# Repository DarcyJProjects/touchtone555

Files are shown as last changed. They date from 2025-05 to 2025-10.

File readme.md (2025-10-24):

# TouchTone555 – NE555 Analogue Stylus Synth

The **TouchTone555** is a fully analogue, NE555-based synthesizer designed for learning about analogue electronics, and a bit of fun too. It was built from scratch as a personal deep-dive into oscillators, signal integrity, analogue filtering, and amplification.

Read the full project write up at: [www.darcyjprojects.xyz](https://www.darcyjprojects.xyz/index.php/2025/04/07/analogue-synth-project-touchtone555/)

[🔗 Share this project on LinkedIn](https://www.linkedin.com/shareArticle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!)



<p>
  This project is open source hardware under the <strong>CERN Open Hardware Licence Version 2 - Strongly Reciprocal (CERN-OHL-S v2)</strong>.
</p>
Open Source Hardware Logo

⚖️**Disclaimer:** This synthesizer was developed as a purely educational project to explore analogue electronics and sound synthesis. It is an independent work inspired by the vintage Stylophone, with no affiliation to Dubreq Ltd. or the original Stylophone product. All trademarks remain the property of their respective owners, and no copyright or trademark infringement is intended.

---

## 📑 Table of Contents

* 🎛 [Features](#-features)

* 📷 [Demo](#-demo)

* 📜 [Licence](#-licence)

* ⚡[How It Works](#how-it-works)

* 🛠️ [Build Instructions](#%EF%B8%8F-build-instructions)
  
  * 🧾 [What You’ll Need](#-what-youll-need)
  
  * 🪛 [Assembly](#-assembly)

* 📂 [Repo Structure](#-repo-structure)

* 💬 [Feedback & Contributions](#-feedback--contributions)

* 🔗 [Acknowledgements](#-acknowledgements)

* 🧠 [Why I Built This](#-why-i-built-this)

---

## 🎛 Features

- Based on the NE555 in astable multivibrator configuration as the main audio oscillator
- Individually tuneable keys with trim potentiometers
- Touch interface for the keys with a stylus
- Octave switching via capacitor bank selection
- Vibrato modulation using an RC oscillator on the 555's CV pin
- Push-pull amplifier output with an LM386 buffer stage
- Onboard speaker with volume control, as well as a headphone output
- Custom designed PCB, with a descriptive silkscreen



---

## 📷 Demo

Check out the demo video here:<br>
👉 [Watch the video](https://www.youtube.com/watch?v=lvPiY5EYj-0)<br>
[](https://www.youtube.com/watch?v=lvPiY5EYj-0)<br>
🎵 Features a cover of Littleroot Town from Pokémon.

---

## 📜 Licence

This project is licenced under the **CERN-OHL-S v2 Strongly Reciprocal**.  

You are free to:

- **Study** and **modify** the design.

- **Make** and **sell** your own copies.

- **Distribute** modified versions — **as long as you:**
  
  - **Use the same CERN-OHL-S v2 licence** (strong reciprocity), and
  
  - **Provide attribution to the original author**, and
  
  - **Include the original source files and any modifications**.

For full details, see the [LICENCE.txt](https://github.com/DarcyJProjects/touchtone555/blob/main/LICENCE.txt) file.



---

## ⚡How It Works

The TouchTone555 generates sound using an NE555 timer IC which is configured as an astable multivibrator. 

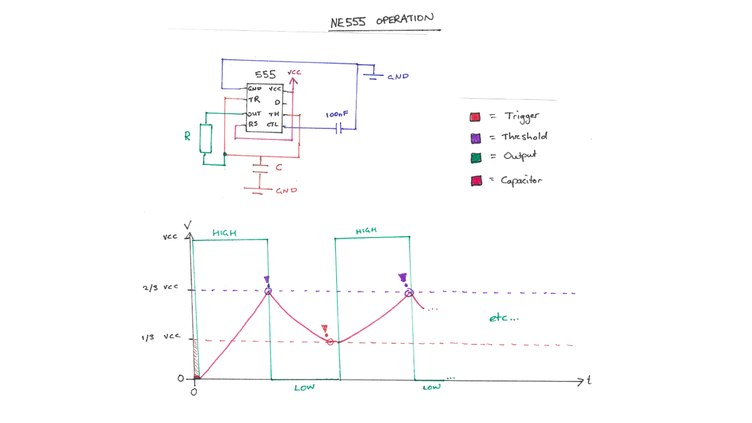
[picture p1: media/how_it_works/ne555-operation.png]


Each key forms part of a series resistor network, which controls the oscillator’s frequency when the circuit is completed by touching a key with the stylus. The pitch is determined by which key is touched, and the selected octave capacitor.

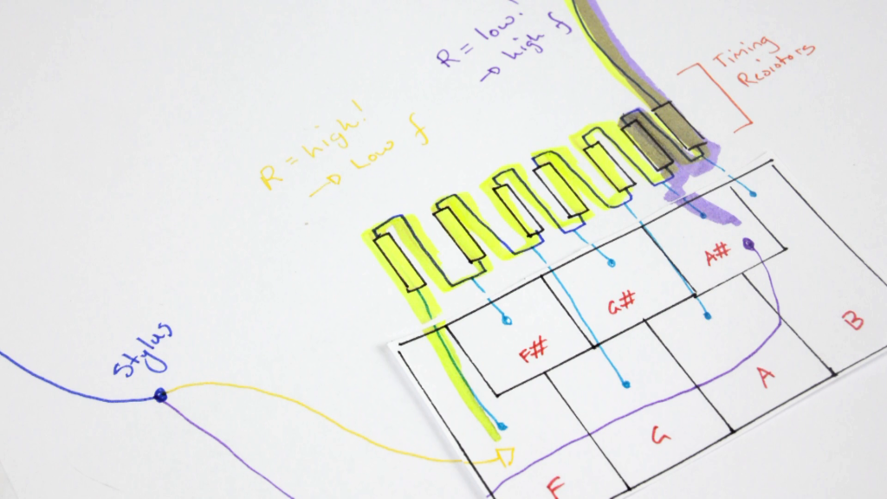
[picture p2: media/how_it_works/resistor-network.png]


Octave switching is achieved by toggling between banks of capacitors connected to the NE555. The more capacitance connected (capacitors in parallel), the lower the resulting octave.

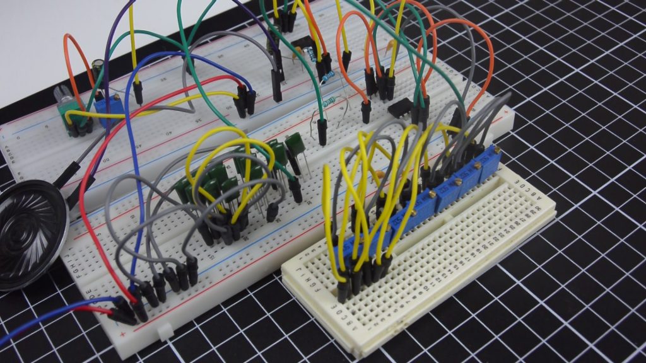
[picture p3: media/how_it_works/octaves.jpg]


Vibrato is achieved by modulating the NE555's control voltage pin using a separate RC oscillator, which uses RC (resistor-capacitor) pairs, capacitors, and a transistor to generate the low-frequency signal. The vibrato depth (or "mix") can be adjusted with the on-board trim potentiometer.



The output signal is then passed through an LM386 and then through a simple push-pull amplifier to drive the onboard speaker and/or headphones. The LM386 acts as a buffer to ensure any loading from the amplifier doesn't affect the NE555 through its output pin. The supply voltage to the NE555 is also filtered with a resistor and capacitor to reduce any periodic voltage drop introduced by the amplifier.

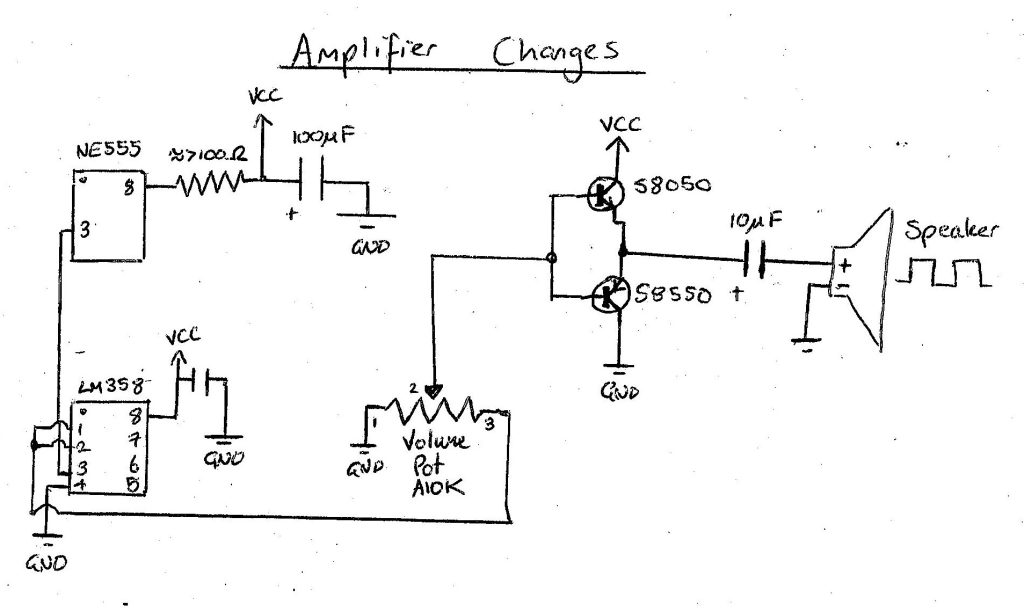
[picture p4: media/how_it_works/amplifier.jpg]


The power supply circuitry is simple: it supports a 9V DC input via either a JST connector, or a DC barrel jack. Two diodes prevent reverse polarity and ensure that the inputs cannot backfeed each other. 

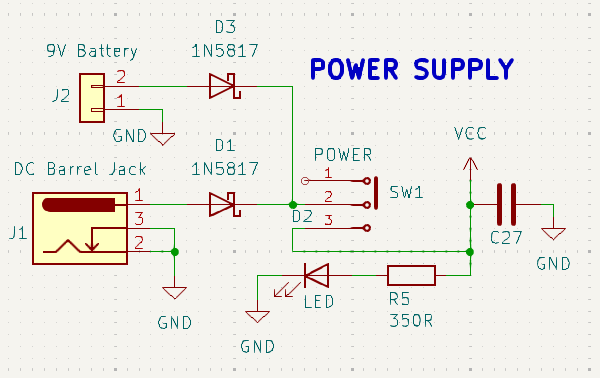
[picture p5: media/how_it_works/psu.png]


This project demonstrates the core concepts of oscillation, modulation, and amplification - no microcontroller required!

👉 For a full breakdown and more detail explanations, you can read the write-up here: [www.darcyjprojects.xyz](https://www.darcyjprojects.xyz/index.php/2025/04/07/analogue-synth-project-touchtone555/)

---

## 🛠️ Build Instructions



### 🧾 What You’ll Need

- All components as outlined in the [BOM (Bill-of-Materials)](https://github.com/DarcyJProjects/touchtone555/blob/main/hardware/bom.md)
- To find the correct switches, speaker, audio jack, etc, see [Miscellaneous Parts](https://github.com/DarcyJProjects/touchtone555/blob/main/hardware/misc_parts.md)
- PCB (See [KiCad Project](https://github.com/DarcyJProjects/touchtone555/tree/main/hardware))
- Soldering iron and solder
- 9V Battery and connector or DC jack with 9V supply

⚠️ **Note:** I recommend selecting a **lead-free surface finish** (e.g., LeadFree HASL) when ordering the PCB as the stylus will put microscopic scratches in the exposed key pads during use. This could potentially produce harmful lead dust over time. Therefore, I highly recommend choosing lead-free!

### 🪛 Assembly

- Read each step fully before completing it to make sure you've read any handy tips :)
1. **Order the PCB**<br>
   The KiCad project files (and pre-exported gerber files) are located in [/hardware](https://github.com/DarcyJProjects/touchtone555/tree/main/hardware).

2. **Solder components in order**<br>
   Start with the smallest passive components (resistors, monolithic capacitors, diodes), then IC sockets, transistors, connectors/jacks/switches, ceramic and polyester capacitors, and finally the DC jack, trim potentiometers and the volume potentiometer.
   
   Soldering them systematically from smallest height to largest makes it a lot easier! Follow the component designators on the board, and in the BOM to make sure you are matching the correct values and components.
   
   Try your best not to get any solder on the exposed key pads, if you're nervous, you  can tape over them with some electrical or painters tape until you're finished soldering.
   
   For the polyester octave capacitors, try to get the values matched to each other as closely as possible as a small variance of 0.5 nF can throw off the pitch. This is less important for the lower octaves, but the highest octave with the single capacitor matters the most.
   
   For the vibrato monolithic capacitors, you can start with soldering the top three in, and adding the lower two if you want increase the vibrato frequency.

3. **Attach speaker & power**<br>
   The synth is designed to run on 9VDC, so I recommend using a 9V battery with a 9V battery to JST connector.

4. **Stylus**<br>
   
   In [/hardware](https://github.com/DarcyJProjects/touchtone555/tree/main/hardware), there is a 3D model of a stylus if you'd like to 3D print one, otherwise, a crocodile lead works really well too - just be careful not to push down too aggressively as to not damage the key pads.
   
   If you take the 3D model route, you can feed a thin gauge wire through the hole in the centre of the stylus, and solder a small piece of metal to the wire at the tip of the stylus. I used a mini spade connector which I soldered and then bent around the tip. I smoothed out the contact surface by creating a sphere of solder. You'll need to tape the tip to the stylus to ensure it doesn't come off. This stylus isn't perfect, but it works :)

5. **Tune keys**<br>
   Use a tuner app (with a chromatic mode) or oscilloscope to set the individual key pitches via the blue trim potentiometers.
   
   Set the octave to the lowest octave (lowest position on the octave switch) and then start tuning with the highest note on the keyboard, which corresponds to the right-most trim pot. Turning it clockwise will increase the pitch, and anticlockwise will decrease the pitch. You are aiming for the highest note (in the lowest octave) to be E6.
   
   Then work your way leftwards, one potentiometer at a time, reducing the pitch by one semitone each time.
   
   Remember, as this is a series resistor network, adjusting the pitch of one potentiometer will adjust the pitch of all the other keys to the left of that key. This is why you should work right to left.

6. **Vibrato depth**<br>
   By turning the vibrato depth trim pot, you can slightly adjust how strong the vibrato effect is. The change with each turn is minimal, so you'll need to turn it a lot to get any real difference. 

7. **Have fun!**

---

## 📂 Repo Structure

TouchTone555/<br>├── hardware/ # KiCad project + Gerbers + Stylus 3D model<br>├── media/ # Photos, demo videos, renders, etc<br>├── LICENCE # CERN-OHL-S v2<br>└── README.md # this file!<br>

---

### 💬 Feedback & Contributions

Feel free to fork, share, and build your own!<br>
If you build one, I’d love to see it - tag me on [LinkedIn](https://www.linkedin.com/in/darcywdjohnson/).

---

### 🔗 Acknowledgements

- This is an independent work inspired by the classic Stylophone with no affiliation to Dubreq Ltd. or the original Stylophone product. All trademarks remain the property of their respective owners, and no copyright or trademark infringement is intended.
- "Littleroot Town", composed by Gō Ichinose, Junichi Masuda, & Morikazu Aoki, from *Pokémon Ruby, Sapphire, & Emerald* (© Nintendo / Game Freak), is used under fair use as part of an educational demonstration.

---

## 🧠 Why I Built This

This was a personal challenge to push my understanding of analogue electronics beyond textbooks — especially in:

- Oscillator design
- Filtering
- Operational amplifiers
- Audio amplifiers
- Impedance buffering
- PCB design with custom exposed planes (the key pads)
- PCB footprint design


---

🛠️ Built for learning.<br>
❤️ Shared with the community.<br>
🔧 Darcy — [www.darcyjprojects.xyz](https://www.darcyjprojects.xyz)

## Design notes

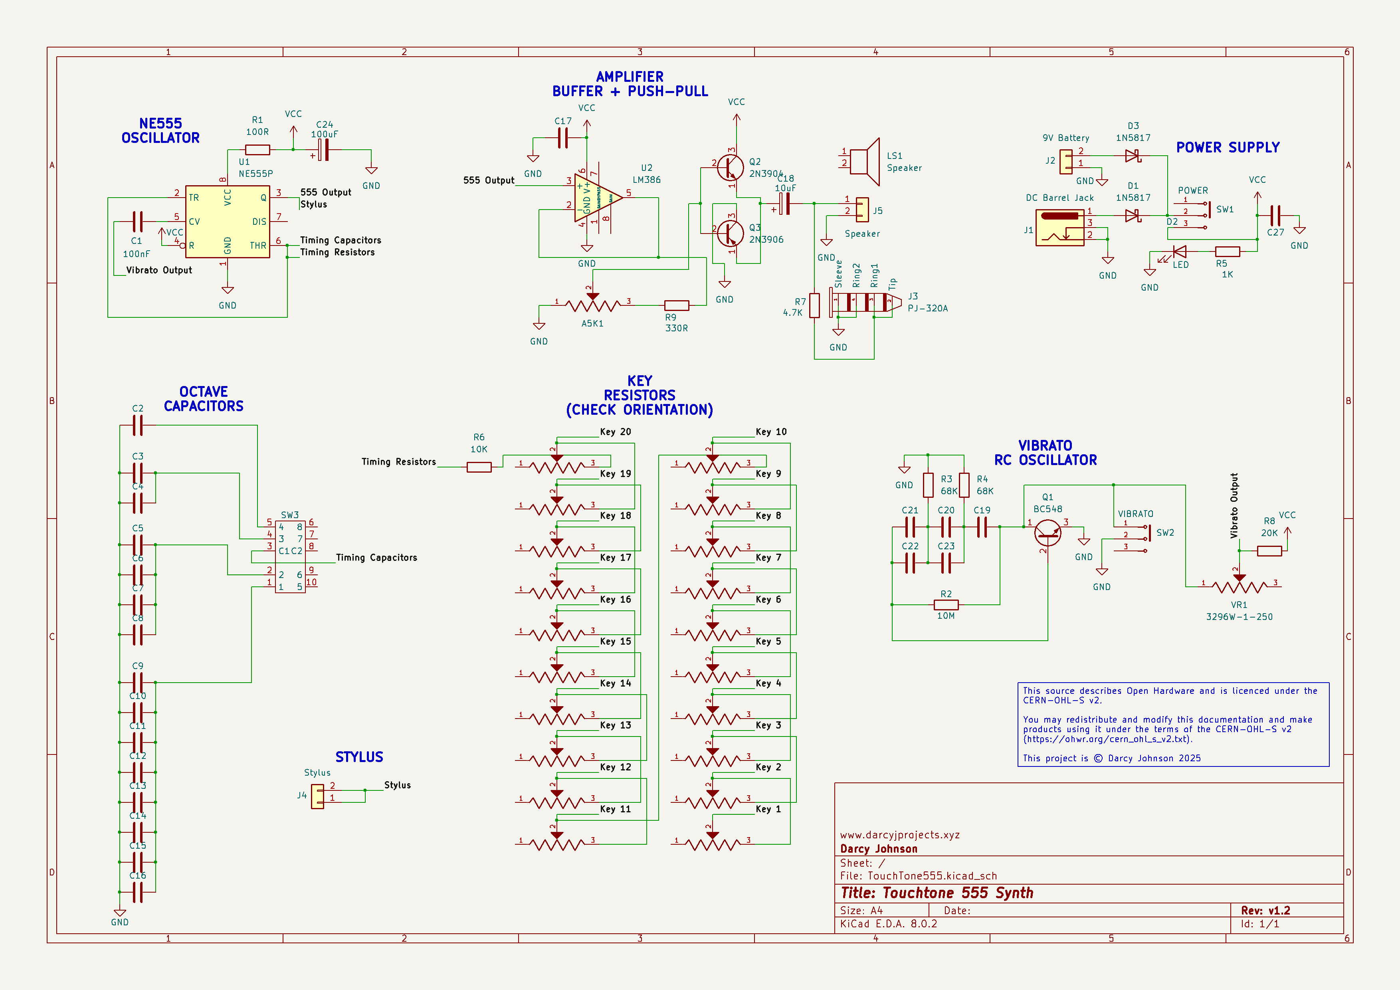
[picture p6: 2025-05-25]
media/schematic.png

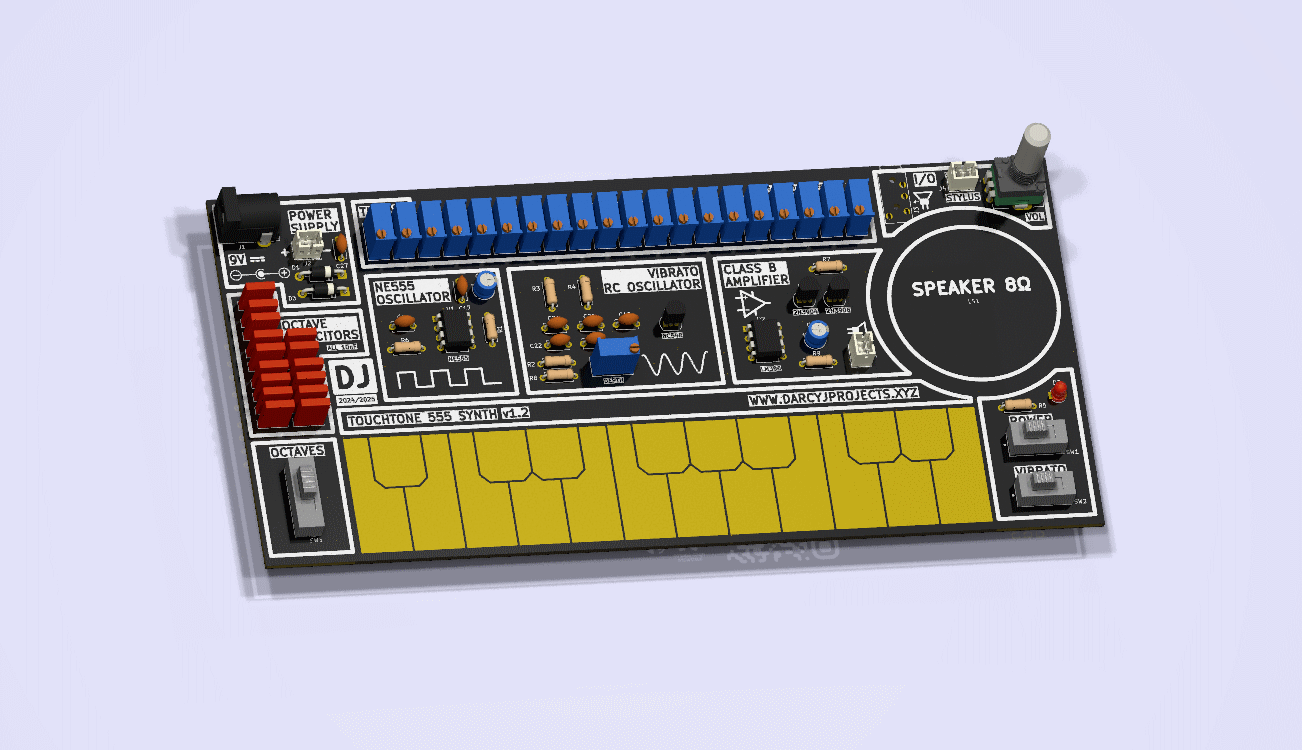
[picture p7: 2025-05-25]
media/board render.png

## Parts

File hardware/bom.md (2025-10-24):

# BOM– TouchTone555

This file lists the Bill of Materials (BOM) - the components required to complete this project.
The regular csv BOM can be viewed here: [Bill of Materials.csv](https://github.com/DarcyJProjects/touchtone555/blob/main/hardware/Bill%20of%20Materials.csv)

---

## Semiconductors

| Qty | Part | Notes |
| --- | --- | --- |
| 2 | 1N5817 | Schottky diode, DO-41 |
| 1 | 2N3906 | PNP, TO-92 |
| 1 | 2N3904 | NPN, TO-92 |
| 1 | BC548 | NPN, TO-92 |
| 1 | LM386 | DIP-8 |
| 1 | NE555P | DIP-8 |
| 1 | LED (any colour) | 3 mm |

### Resistors

| Qty | Value  |
| --- | --- |
| 1 | 100 Ω  |
| 1 | 330 Ω  |
| 1 | 1 kΩ |
| 2 | 10 kΩ  |
| 2 | 68 kΩ  |
| 1 | 4.7 kΩ |
| 1 | 10 MΩ  |

### Potentiometers / Trimmers

| Qty | Type | Value / Model | Notes |
| --- | --- | --- | --- |
| 20  | Trimmer (3296W) | 5 kΩ | |
| 1 | Trimmer (3296W) | 10 kΩ | |
| 1 | Rotary Potentiometer (A5K RK097) | 5 kΩ | [**See Misc Parts**](https://github.com/DarcyJProjects/touchtone555/blob/main/hardware/misc_parts.md) |

### Capacitors

| Qty | Value  | Type / Notes |
| --- | --- | --- |
| 15  | 10 nF  | Green polyester capacitors (rectangular) - do not use ceramic (poor stability). |
| 8 | 100 nF | Ceramic disc |
| 1 | 10 µF  | Electrolytic, radial |
| 1 | 100 µF | Electrolytic, radial |

### Connectors and Jacks

| Qty | Part | Description |
| --- | --- | --- |
| 1 | DC Barrel Jack | [**See Misc Parts**](https://github.com/DarcyJProjects/touchtone555/blob/main/hardware/misc_parts.md) |
| 3 | JST-PH 2-pin | Stylus, speaker, and 9 V battery connector |
| 1 | PJ-320A | 3.5 mm audio jack [**See Misc Parts**](https://github.com/DarcyJProjects/touchtone555/blob/main/hardware/misc_parts.md) |

### Switches

| Qty | Part | Description |
| --- | --- | --- |
| 2 | 2 Position Slide Switch (SPDT) | Power and vibrato switch [**See Misc Parts**](https://github.com/DarcyJProjects/touchtone555/blob/main/hardware/misc_parts.md) |
| 1 | 4 Position Slide Switch (2P4T) | Octave switch [**See Misc Parts**](https://github.com/DarcyJProjects/touchtone555/blob/main/hardware/misc_parts.md) |

### Speaker

| Qty | Part | Description |
| --- | --- | --- |
| 1 | Speaker | 8 Ω, 2W 40 mm [**See Misc Parts**](https://github.com/DarcyJProjects/touchtone555/blob/main/hardware/misc_parts.md) |

---

> 💡 *Note:* Compare parts with the build photos, schematic, and PCB layout to check for correct footprints and sizes. The components listed here are only suggestions and are not guaranteed. Check misc parts file for a detailed look at the less standard components.

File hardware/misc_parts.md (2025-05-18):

# Miscellaneous Components – TouchTone555

This file lists the less standard components that may have slight variations from different sellers, so this information is to help you find the correct parts. The information and photos was taken from the listings I bought the items from (no copyright infringement intended).

---

## Switches

### 🔘 2-Position Slide Switches

- **Name:** Generic mini slide switch
- **Type:** SPDT toggle
- **Voltage:** 5V
- **Current:** 0.3A
- **Used for:** Power switch, Vibrato switch
- **Dimensions (LxWxH):** Approx. 19 x 6 x 13 mm
- **AliExpress:** [https://www.aliexpress.com/item/32812689209.html](https://www.aliexpress.com/item/32812689209.html)

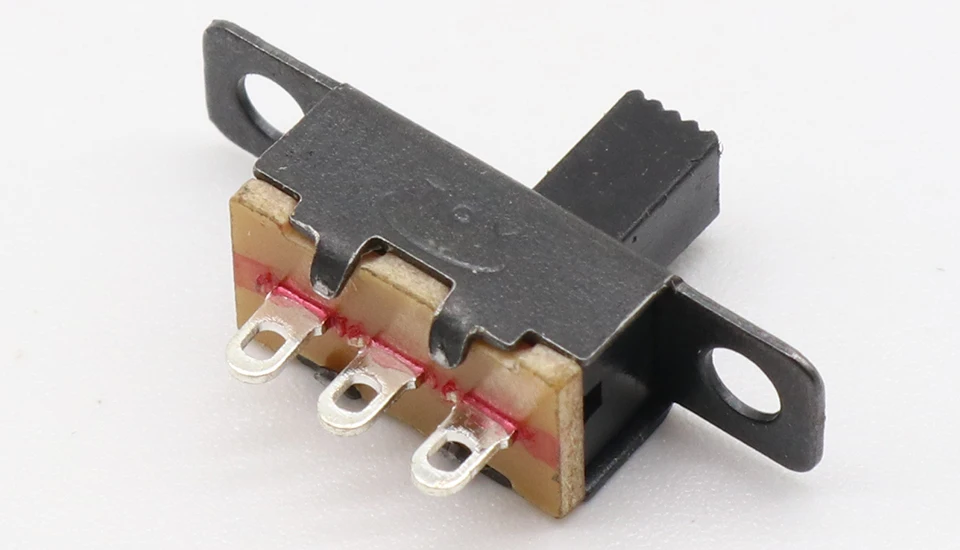
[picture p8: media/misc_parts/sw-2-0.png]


### 🔘 4-Position Slide Switches

- **Name:** SS-24E04 2P4T DIP Type Slide Switch 10 pin
- **Type:** 2P4T
- **Used for:** Octave switch
- **AliExpress:** [https://www.aliexpress.com/item/1005004678559173.html](https://www.aliexpress.com/item/1005004678559173.html)

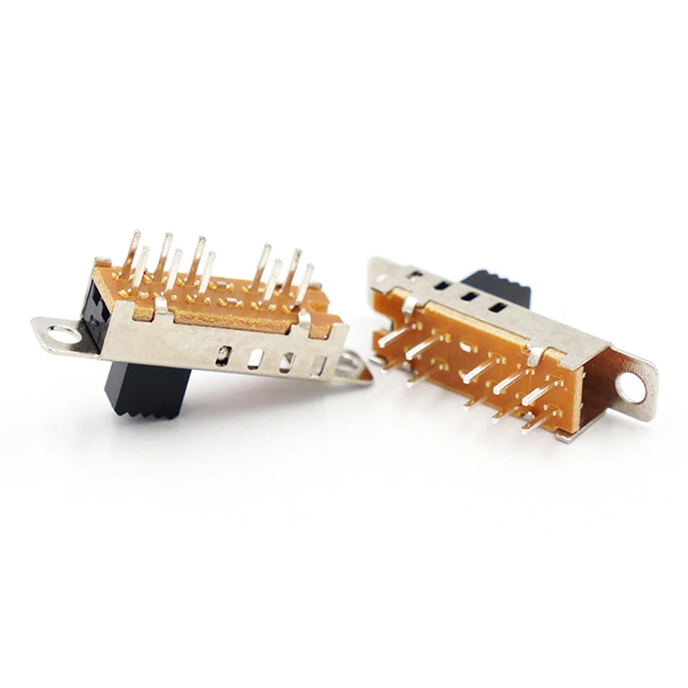
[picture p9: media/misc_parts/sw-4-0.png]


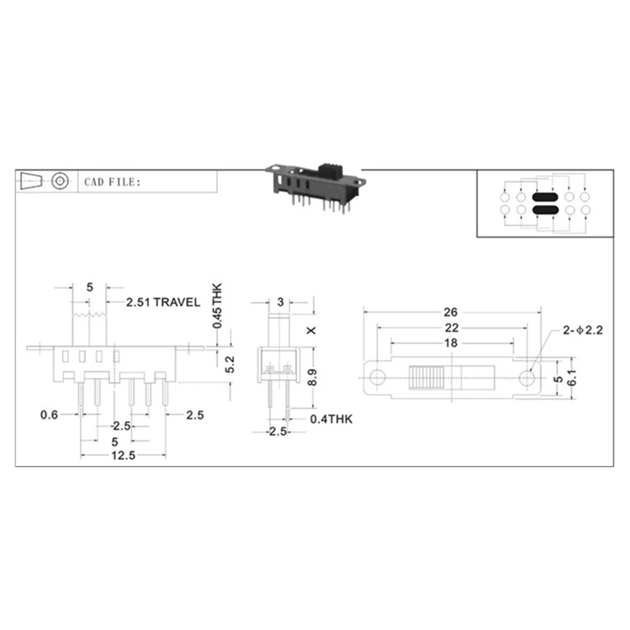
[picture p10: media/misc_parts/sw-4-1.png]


---

## 🔊 Speaker

- **Type:** 8Ω 2W
- **Diameter:** 40 mm
- **AliExpress:** [https://www.aliexpress.com/item/1005006730077789.html](https://www.aliexpress.com/item/1005006730077789.html)

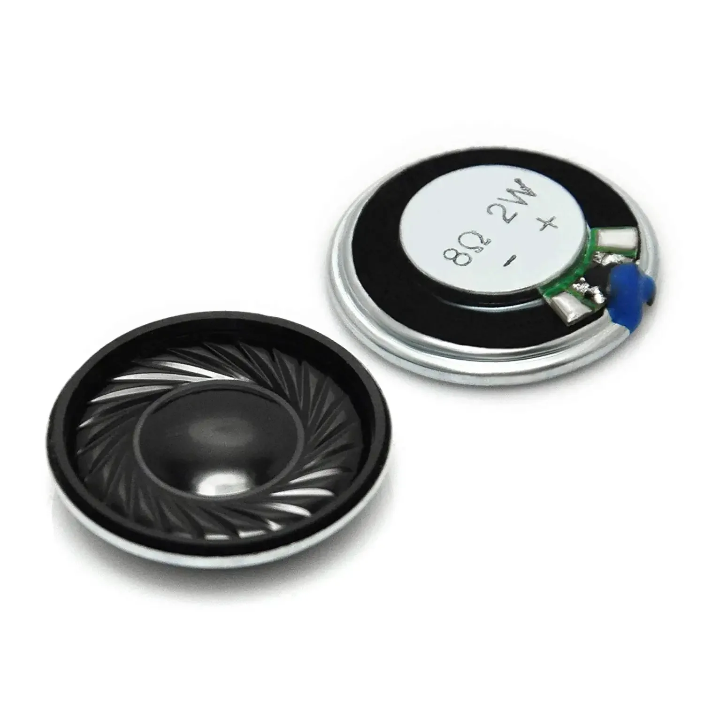
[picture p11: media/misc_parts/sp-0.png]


---

## 🎚️ Volume Potentiometer

- **Type:** B10K (Linear Rotary Potentiometer)
- **Model:** RV09
- **Shaft:** 12.5 mm
- **AliExpress:** [https://www.aliexpress.com/item/1005006089154415.html](https://www.aliexpress.com/item/1005006089154415.html)

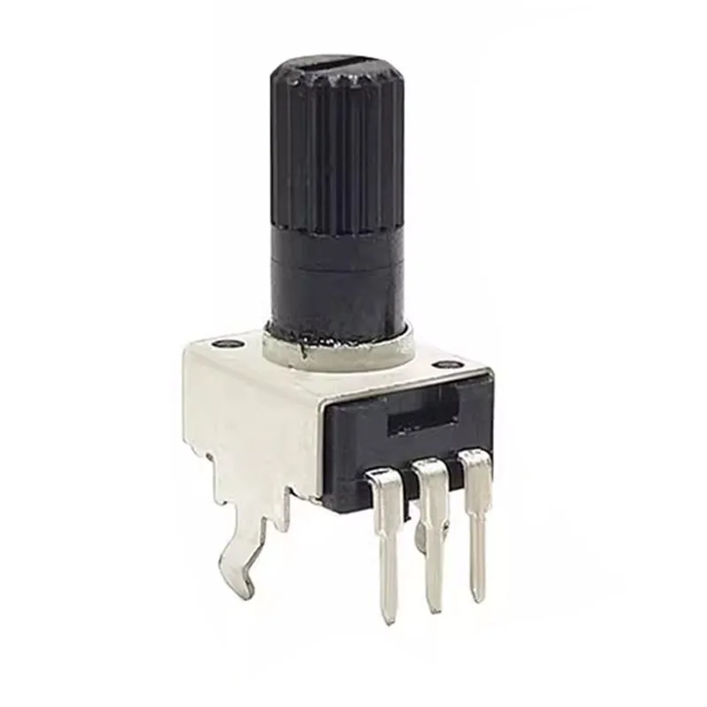
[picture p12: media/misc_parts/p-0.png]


---

## 🎧 Headphone Jack

- **Type:** 3.5 mm stereo audio jack
- **Model:** PJ320A
- **AliExpress:** [https://www.aliexpress.com/item/1005003111662179.html](https://www.aliexpress.com/item/1005003111662179.html)

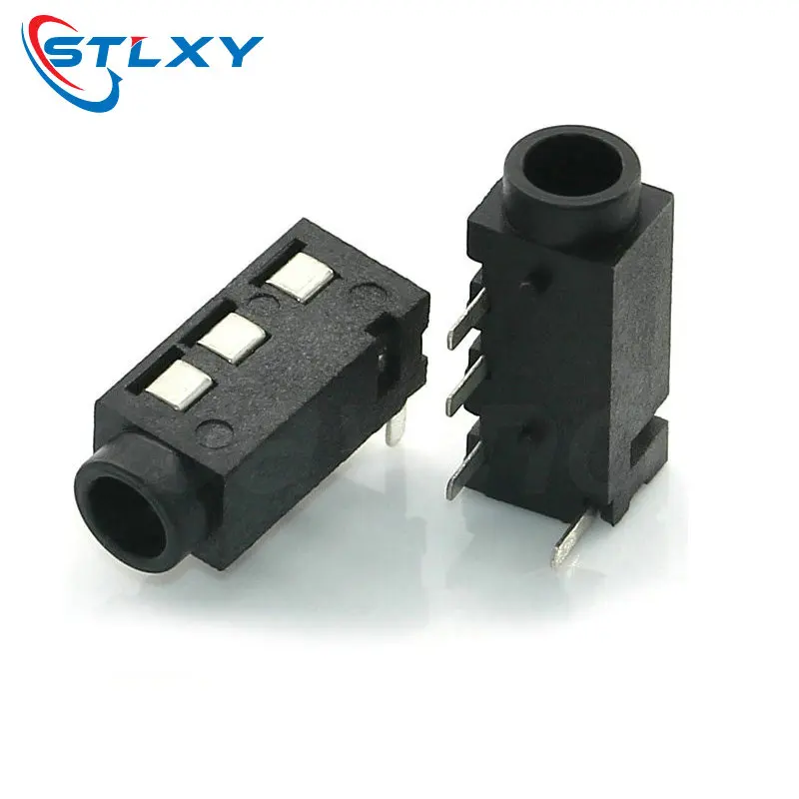
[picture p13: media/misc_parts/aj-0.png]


---

## 🔌 DC Power Jack

- **Name:** DC Power Jack Socket Barrel Right Angle
- **AliExpress:** [https://www.aliexpress.com/item/4001206395694.html](https://www.aliexpress.com/item/4001206395694.html?)

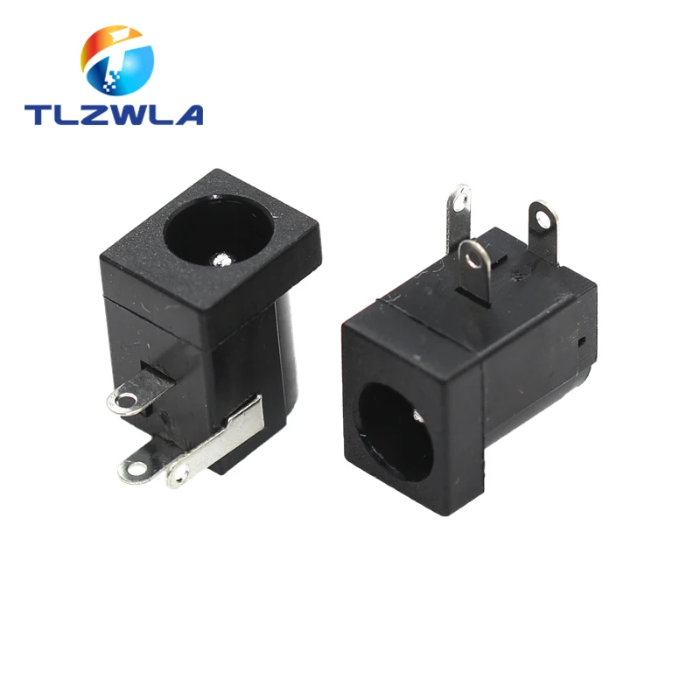
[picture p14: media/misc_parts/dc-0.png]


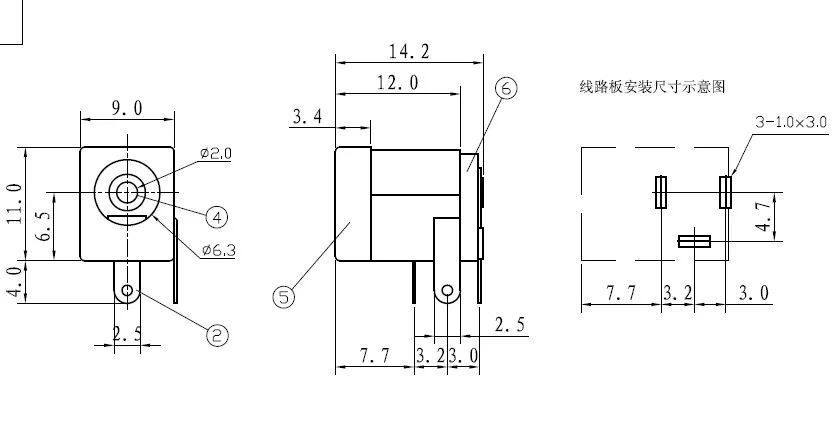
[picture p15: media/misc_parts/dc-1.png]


---

> 💡 *Note:* Exact part numbers and models may vary by region or vendor. These suggestions are the listings I bought my parts from, however, the stock may have changed since my purchase, so carefully reference the PCB footprints and schematic values before purchasing. The components listed here are only suggestions and are not guaranteed.

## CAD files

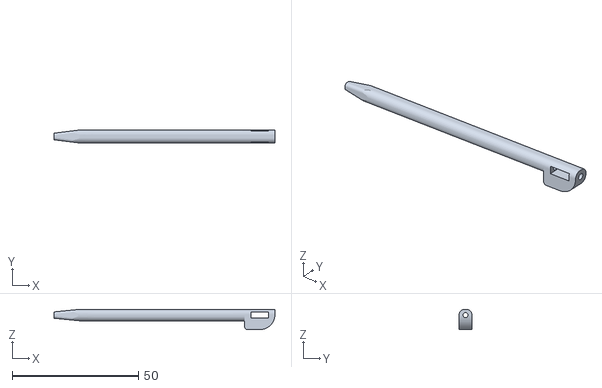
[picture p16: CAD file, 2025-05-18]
hardware/stylus.stl
87.5 x 5.00 x 8.00

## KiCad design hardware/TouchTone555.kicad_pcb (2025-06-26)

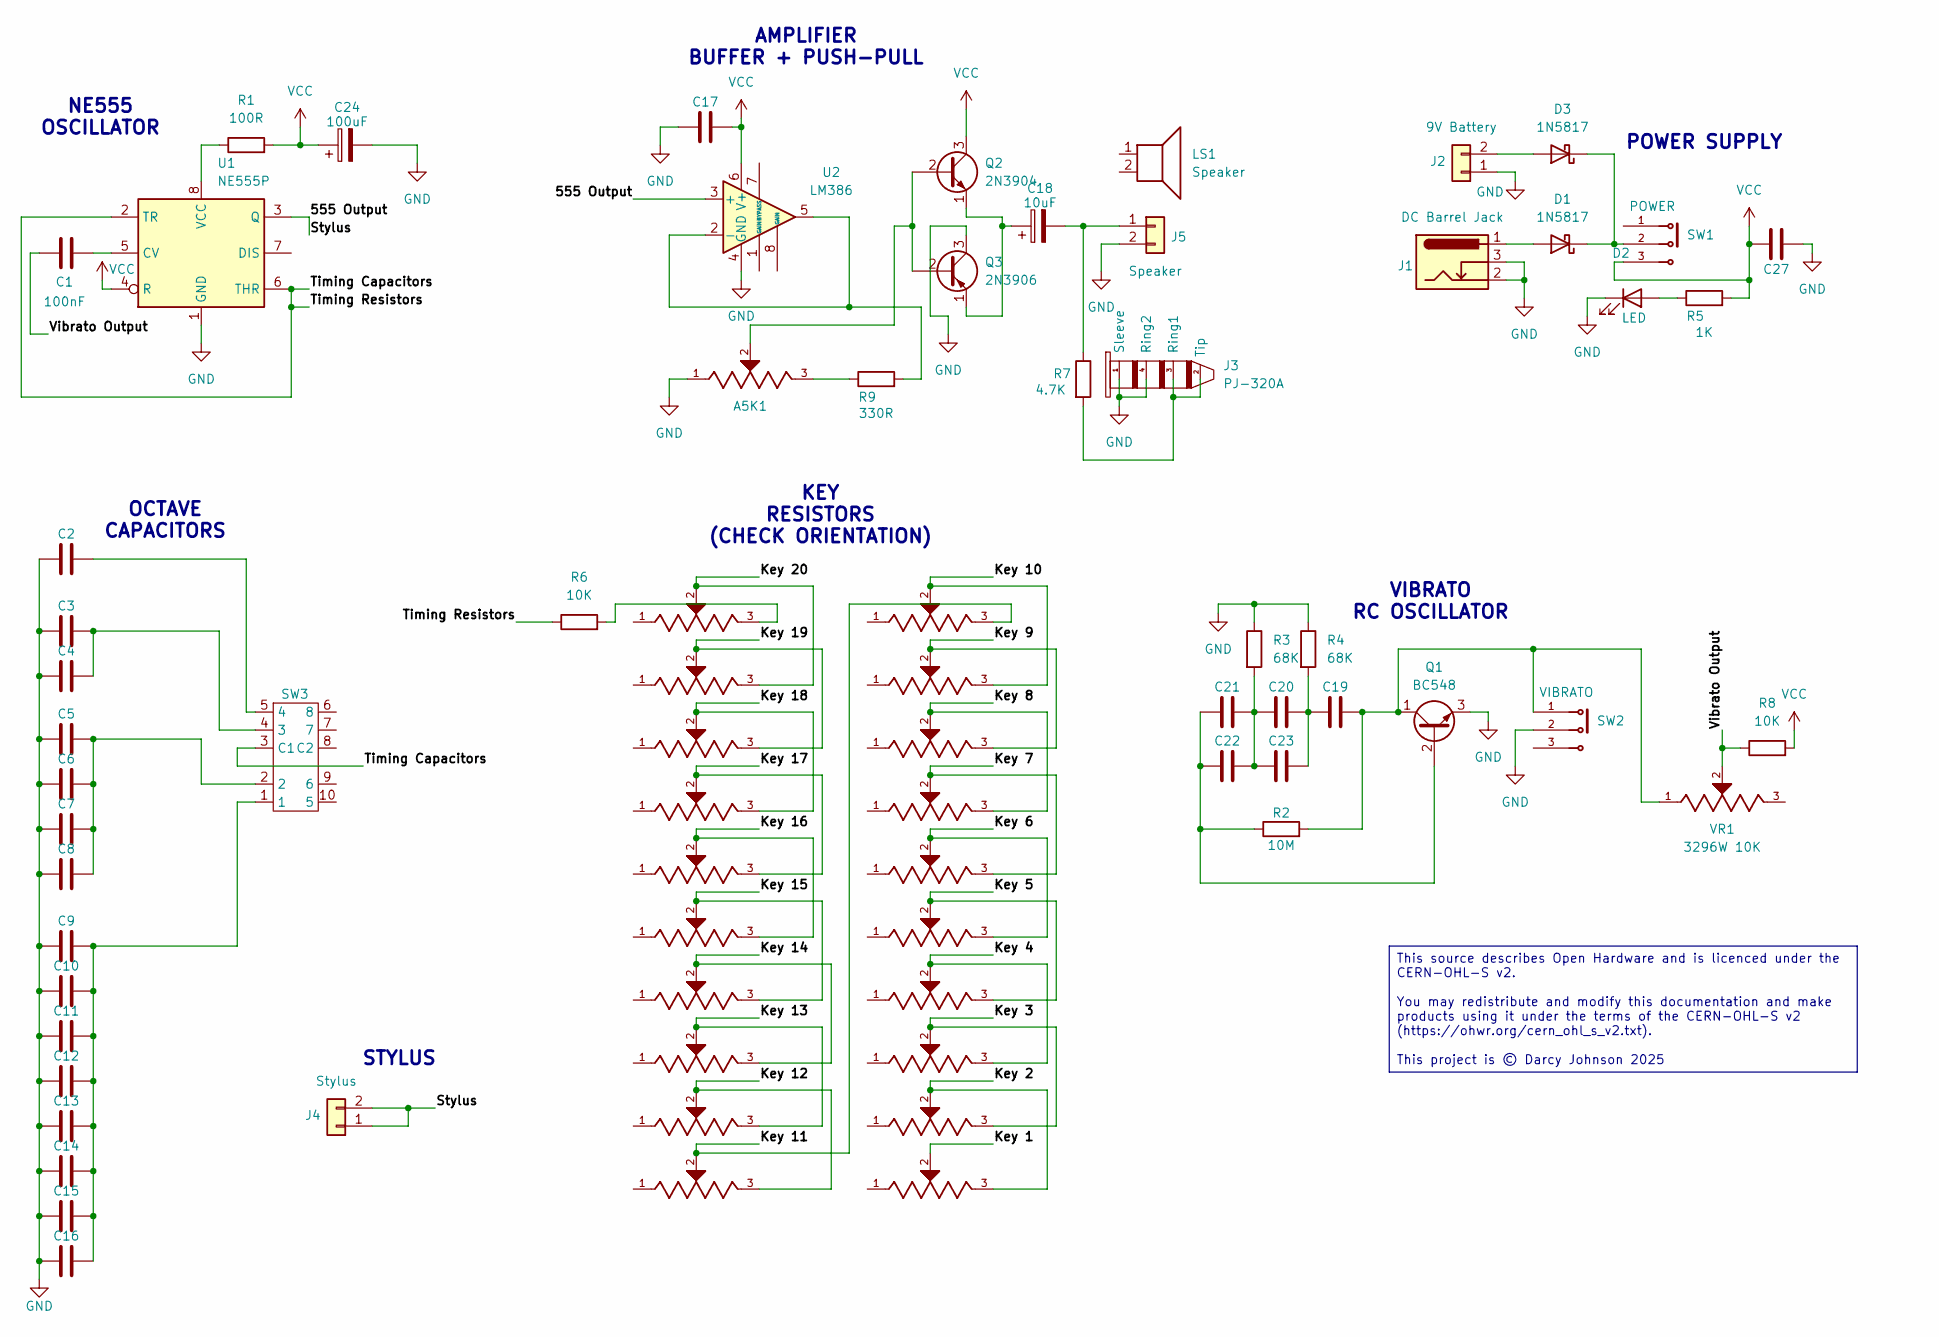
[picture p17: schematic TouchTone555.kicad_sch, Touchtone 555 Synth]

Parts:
A5K1: A5K RK097; RV09 Vertical Aliexpress; PARTREV 05/16
C1, C17, C19, C20, C21, C22, C23, C27: 100nF; C_Disc_D5.0mm_W2.5mm_P5.00mm
C2, C3, C4, C5, C6, C7, C8, C9, C10, C11, C12, C13, C14, C15, C16: 10nF; C_Rect_L7.0mm_W2.0mm_P5.00mm
C18: 10uF; CP_Radial_D5.0mm_P2.50mm
C24: 100uF; CP_Radial_D5.0mm_P2.50mm
D1, D3: 1N5817; D_DO-41_SOD81_P10.16mm_Horizontal
D2: LED; LED_D3.0mm
J1: DC Barrel Jack; BarrelJack_CUI_PJ-102AH_Horizontal_BIGGER_HOLES
J2: 9V Battery; JST_PH_B2B-PH-K_1x02_P2.00mm_Vertical
J3: PJ-320A
J4: Stylus; JST_PH_B2B-PH-K_1x02_P2.00mm_Vertical
J5: Speaker; JST_PH_B2B-PH-K_1x02_P2.00mm_Vertical
LS1: Speaker; 8Ω Speaker 40mm
Q1: BC548; TO-92_Inline
Q2: 2N3904; TO-92_Inline
Q3: 2N3906; TO-92_Inline
R1: 100R; R_Axial_DIN0207_L6.3mm_D2.5mm_P7.62mm_Horizontal
R2: 10M; R_Axial_DIN0207_L6.3mm_D2.5mm_P7.62mm_Horizontal
R3, R4: 68K; R_Axial_DIN0207_L6.3mm_D2.5mm_P7.62mm_Horizontal
R5: 1K; R_Axial_DIN0207_L6.3mm_D2.5mm_P7.62mm_Horizontal
R6, R8: 10K; R_Axial_DIN0207_L6.3mm_D2.5mm_P7.62mm_Horizontal
R7: 4.7K; R_Axial_DIN0207_L6.3mm_D2.5mm_P7.62mm_Horizontal
R9: 330R; R_Axial_DIN0207_L6.3mm_D2.5mm_P7.62mm_Horizontal
SW1: POWER; SW_1825159-1; MPN 1825159-1
SW2: VIBRATO; SW_1825159-1; MPN 1825159-1
SW3: SS-24E04_2P4T_Slide_Switch
U1: NE555P; DIP-8_W7.62mm
U2: LM386; DIP-8_W7.62mm
VR1: 3296W 10K; Potentiometer_Bourns_3296W_Vertical; PARTREV 05/16
VR2, VR3, VR4, VR5, VR6, VR7, VR8, VR9, VR10, VR11, VR13, VR14, VR15, VR16, VR17, VR18, VR19, VR20, VR21, VR22: 3296W 5K; Potentiometer_Bourns_3296W_Vertical; PARTREV 05/16

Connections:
/555 Output: J4.1, J4.2, U1.3 (Q), U2.3 (+)
/Key 1: VR22.2
/Key 2: VR21.2, VR22.3
/Key 3: VR20.2, VR21.3
/Key 4: VR19.2, VR20.3
/Key 5: VR18.2, VR19.3
/Key 6: VR17.2, VR18.3
/Key 7: VR16.2, VR17.3
/Key 8: VR15.2, VR16.3
/Key 9: VR14.2, VR15.3
/Key 10: VR13.2, VR14.3
/Key 11: VR11.2, VR13.3
/Key 12: VR10.2, VR11.3
/Key 13: VR9.2, VR10.3
/Key 14: VR8.2, VR9.3
/Key 15: VR7.2, VR8.3
/Key 16: VR6.2, VR7.3
/Key 17: VR5.2, VR6.3
/Key 18: VR4.2, VR5.3
/Key 19: VR3.2, VR4.3
/Key 20: VR2.2, VR3.3
/Timing Capacitors: R6.1, SW3.3 (C1), U1.2 (TR), U1.6 (THR)
/Vibrato Output: C1.2, R8.1, VR1.2
GND: A5K1.1, C2.1, C3.1, C4.1, C5.1, C6.1, C7.1, C8.1, C9.1, C10.1, C11.1, C12.1, C13.1, C14.1, C15.1, C16.1, C17.1, C24.2, C27.1, D2.1 (K), J1.2, J1.3, J2.1, J3.1 (Sleeve), J3.4 (Ring2), J5.2, Q1.3 (E), Q3.3 (C), R3.1, R4.1, SW2.2, U1.1 (GND), U2.4 (GND)
unnamed: A5K1.3, R9.1
unnamed: C5.2, C6.2, C7.2, C8.2, SW3.2
unnamed: C9.2, C10.2, C11.2, C12.2, C13.2, C14.2, C15.2, C16.2, SW3.1
unnamed: C19.1, C20.2, C23.2, R4.2
unnamed: C20.1, C21.2, C22.2, C23.1, R3.2
unnamed: D1.2 (A), J1.1
unnamed: D1.1 (K), D3.1 (K), SW1.2
unnamed: D2.2 (A), R5.1
unnamed: D3.2 (A), J2.2
unnamed: J3.2 (Tip), J3.3 (Ring1), R7.2
unnamed: C18.2, J5.1, R7.1
unnamed: C21.1, C22.1, Q1.2 (B), R2.1
unnamed: C19.2, Q1.1 (C), R2.2, SW2.1, VR1.1
unnamed: A5K1.2, Q2.2 (B), Q3.2 (B)
unnamed: C18.1, Q2.1 (E), Q3.1 (E)
unnamed: R6.2, VR2.3
unnamed: C3.2, C4.2, SW3.4 (3)
unnamed: C2.2, SW3.5 (4)
unnamed: C1.1, U1.5 (CV)
unnamed: R1.1, U1.8 (VCC)
unnamed: R9.2, U2.2 (-), U2.5
VCC: C17.2, C24.1, C27.2, Q2.3 (C), R1.2, R5.2, R8.2, SW1.3, U1.4 (R), U2.6 (V+)

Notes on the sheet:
NE555 OSCILLATOR
STYLUS
VIBRATO RC OSCILLATOR
KEY RESISTORS (CHECK ORIENTATION)
OCTAVE CAPACITORS
AMPLIFIER BUFFER + PUSH-PULL
POWER SUPPLY
This source describes Open Hardware and is licenced under the CERN-OHL-S v2. You may redistribute and modify this documentation and make products using it under the terms of the CERN-OHL-S v2 (https://ohwr.org/cern_ohl_s_v2.txt). This project is © Darcy Johnson 2025

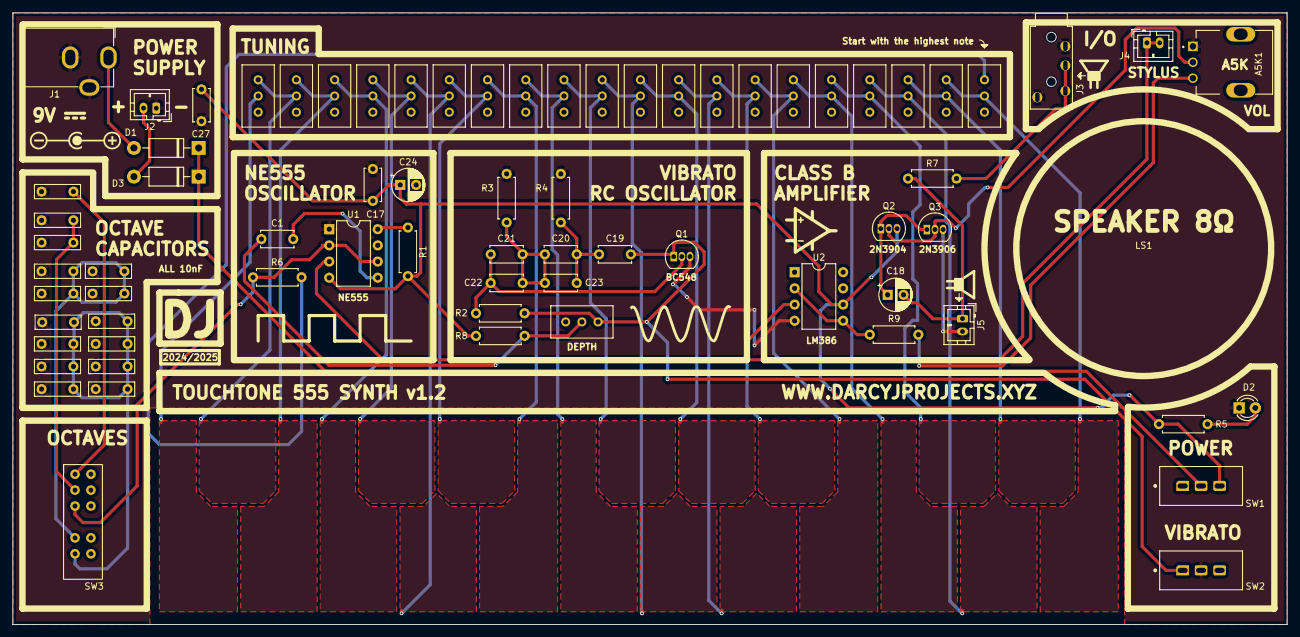
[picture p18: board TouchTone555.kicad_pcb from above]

Board: 2 copper layers, 200.0 x 96.0 mm, 73 parts (0 on the bottom side), 45 nets.

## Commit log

2025-05-17 Upload KiCad project, fabrication files
    [Bill of Materials.csv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]
2025-05-18 Stylus model, how it works
    [stylus.stl]
2025-05-25 Add board render, schematic
2025-06-26 Fixed values for trim pots & R8
    Tuning trim potentiometers were incorrectly listed as 10K, have been changed to 5K.
    Vibrato trim potentiometer was incorrectly listed as 250R, has been changed to 10K.
    R8 was incorrectly listed as 20K, should be 10K.
    [Bill of Materials.csv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]
2025-10-24 Added a bom.md file
    Easier to read than csv.
2025-10-24 Update readme.md
    Updated BOM link to md rather than csv
2025-10-24 Update bom.md
    Added links to misc_parts.md
